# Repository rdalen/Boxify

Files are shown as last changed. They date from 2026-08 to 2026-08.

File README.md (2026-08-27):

# 📦 Boxify

**Parametric Electronics Enclosure Framework (PEEF)** for Onshape.

Boxify provides a reusable, configuration-driven framework for creating custom enclosures around PCB-based electronics

Instead of designing an enclosure directly around a specific PCB, Boxify separates the electronics from the enclosure through a **parametric Adapter Plate**.

The result is a reusable enclosure architecture that can adapt to different PCB designs and configurations.

### 📖 Boxify on Instructables

Want a more visual introduction to Boxify?

Check out the Boxify [Instructable](https://www.instructables.com/-Boxify-a-Parametric-Electronics-Enclosure-Framewo) for a step-by-step introduction to the Boxify concept and workflow.

---


<p align="center"><i>Boxify Enclosure design</i></p>

---

# 🔗 Boxify Onshape Document

The parametric CAD model is maintained in Onshape:

👉 **[Open Boxify in Onshape](https://cad.onshape.com/documents/2b9b04247ce552c5f277d796/w/c7290f51dafd6be38e8eb7a9/e/5737f0d6de4e250f9e54ff44)**

The GitHub repository contains the documentation and project history, while the Onshape document contains the parametric CAD model itself.

---

## 🧠 What is Boxify?

Boxify is designed around a simple principle:

> **The PCB defines the electronics. The Adapter Plate defines the mechanical interface. PS Enclosure defines what enclosure to build.**

The architecture separates the different responsibilities:

```text id="2a0p6m"
PCB / KiCad
     │
     │ detailed PCB STEP
     ▼
PS KiCadStep  <--- PCB Library
     │
     │ PCB + reusable PCB Type
     ▼
Adapter Plate
     │
     │ mechanical interface
     ▼
PS Enclosure  <--- Threaded Insert Library
     │
     │ user configuration
     ▼
Box Base + Box Lid
     │
     ▼
Assembly
```

This separation allows:

- The same PCB to be used with different enclosure configurations.
- The same enclosure architecture to support different PCB designs.
- PCB revisions to propagate through the mechanical design.
- Reusable PCB and hardware definitions to be maintained independently.
- Optional enclosure features to be dynamically enabled or suppressed.

---

# 🔗 KiCad Integration

Boxify integrates with KiCad through the PCB STEP export.

The imported STEP model represents the detailed physical PCB assembly.

Boxify uses a **Carrier / Passenger** architecture:

```text id="j3h6vz"
PCB Library
     │
     │ reusable PCB Type
     ▼
   Carrier
     ▲
     │
   Passenger
     │
     │ detailed geometry
     │
 KiCad STEP
```

The PCB Library provides the reusable PCB definition, while the imported STEP model provides the detailed representation of the actual PCB.

This allows the PCB STEP model to be updated independently without breaking the surrounding Boxify architecture, keeping the enclosure design reusable and parametric.

---

# 🏗 Core Architecture

The **Adapter Plate** is the central mechanical abstraction in Boxify.

It separates:

```text id="5q6x2v"
Electronics
    │
    ▼
PCB / KiCad
    │
    ▼
PS KiCadStep
    │
    ▼
Adapter Plate
    │
    ▼
PS Enclosure
    │
    ▼
Enclosure
```

The enclosure therefore does not need to depend directly on the internal structure of the PCB.

The Adapter Plate acts as the **contract between the PCB and the enclosure**.

---

# 📚 Documentation

The documentation is organized by responsibility.

### **[Getting Started](docs/getting-started.md)**
→ *How do I use Boxify?*

A practical introduction to the Boxify workflow, from importing a PCB to configuring and verifying an enclosure.

### **[Architecture](docs/architecture.md)**
→ *How is Boxify structured?*

Explains the overall architecture, responsibilities of each component and the flow of information through the framework.

### **[Configurations](docs/configurations.md)**
→ *How does configuration work?*

Explains user configuration, measured and derived variables, dynamic suppression and the configuration philosophy of Boxify.

### **[PCB Library](docs/pcb-library.md) and [KiCad Integration](docs/kicad-integration.md)**
→ *How do I bring my electronics into it?*

Explains the PCB Library, KiCad STEP integration and the Carrier / Passenger architecture.

### **[Adapter Plate](docs/adapter-plate.md)**
→ *How is the PCB separated from the enclosure?*

Explains the mechanical abstraction layer between the PCB and enclosure.

### **[Enclosure](docs/enclosure.md)**
→ *How is the enclosure generated?*

Explains the Box Base, Box Lid, fastening options, cut-outs, labels and dynamic feature suppression.

### **[Threaded Insert Library](docs/threaded-insert-library.md)**
→ *How are reusable fastening components handled?*

Explains reusable threaded insert definitions and their integration with PS Enclosure.

### **[Contributing](CONTRIBUTING.md)**
→ *How do I extend Boxify?*

Explains the development workflow, architecture principles, testing and contribution guidelines.

---

# ✨ Key Features

### 🧩 Parametric Enclosure

Generate a configurable Box Base and Box Lid from a single enclosure architecture.

### 🔌 KiCad STEP Integration

Use the actual PCB and component geometry exported from KiCad.

### 🚗 Carrier / Passenger Architecture

Separate the reusable PCB definition from the detailed imported STEP model.

### 🔧 Adapter Plate

Use a stable mechanical interface between electronics and enclosure.

### ⚙️ Centralized Configuration

Configure enclosure-related options from PS Enclosure.

### 🔩 Threaded Insert Library

Select reusable threaded insert definitions instead of hard-coding insert geometry into the enclosure.

### 🔄 Dynamic Suppression

Automatically enable or suppress optional features according to the selected configuration.

### 🔌 Interface Cut-outs

Define your own required enclosure cut-outs based on the available PCB/interface geometry. The PCB definition remains unchanged.

### 🏷️ Text Labels

Define your own enclosure-specific labels, independently of the PCB definition.

---

# 📐 Design Philosophy

Boxify follows a few fundamental principles:

### Separation of Responsibilities

Each part of the architecture has a clear purpose.

### Configure Design Intent

Configuration describes **what the user wants to build**, not how the CAD features are implemented.

### Measure Rather Than Duplicate

If geometry already contains the required information, derive or measure it rather than entering the same value again.

### Reusable Components

Reusable definitions belong in libraries.

### Stable References

Downstream geometry should rely on stable mechanical references rather than fragile implementation details.

### Minimal Coupling

The enclosure should depend on the Adapter Plate rather than directly on the PCB implementation.

### Dynamic Configuration

Optional features should be enabled or suppressed according to configuration.

---

# 🛠️ Built With

- **[Onshape](https://www.onshape.com/)** — Parametric CAD
- **[KiCad](https://www.kicad.org/)** — PCB design and STEP export
- **GitHub** — Version control and documentation

---

# 📜 Version History

Boxify follows an evolving configuration-driven architecture. See the [CHANGELOG](CHANGELOG.md) for the development history and architectural changes.

Boxify is currently based on the v2.x configuration-driven architecture, with ongoing improvements to the PCB and KiCad STEP integration.

---

# 🤝 Contributing

Contributions are welcome!

Before making changes, please read the [Contributing Guide](CONTRIBUTING.md) and familiarize yourself with the [Architecture](docs/architecture.md).

---

**Happy Boxifying! 🚀**

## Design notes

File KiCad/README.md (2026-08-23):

# KiCad Resources

These KiCad resources are provided to create PCB designs that match the mechanical definitions in the Boxify PCB Library.

## KiCad Templates

To use a Boxify KiCad template:

1. In KiCad, click **File > New Project from Template...** in the main menu.
2. Choose the **User Templates** source tab. This displays templates you have built or imported yourself.
3. Select one of the Boxify templates. Single-click an icon to view its description, layout constraints, or details.
4. Click **OK** once you have made your choice.
5. **Name and Save:** Provide a name for your design.
6. KiCad will automatically create a new project directory populated with pre-configured schematics, board layout, and design rules.

## KiKit Panelizing Plugin

To use one of the Boxify KiKit panelization configurations:

1. Open **KiCad PCB Editor** (standalone).
2. Start the **KiKit panelizing plugin** by clicking the menu button.
3. In KiKit, import the desired panelization configuration, for example:
   `KiKit panelize 2x PCB w49x100mm.json`
4. Browse for the **Input file**.
5. Browse for the **Output file**.
6. Click **Panelize**.

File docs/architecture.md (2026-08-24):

# 🏗 Architecture

Boxify is a **Parametric Electronics Enclosure Framework (PEEF)** built for Onshape.

The architecture separates the electronics from the mechanical enclosure by introducing an intermediate **Adapter Plate**.

This separation allows:

- The same PCB to be used with different enclosure configurations.
- The same enclosure architecture to support different PCB designs.
- PCB-specific geometry to remain independent from enclosure-specific geometry.
- Enclosure configuration to be managed from a single user-facing location.

The result is a modular, reusable and configuration-driven enclosure framework.

---

# 🔄 Workflow Overview

```text
PCB / KiCad
     │
     │ detailed PCB STEP
     ▼
PS KiCadStep  <--- PCB Library
     │
     │ PCB + reusable PCB Type
     ▼
Adapter Plate
     │
     │ mechanical interface
     ▼
PS Enclosure <--- Threaded Insert Library
     │
     │ user configuration
     ▼
Box Base + Box Lid
     │
     ▼
Assembly
```

The libraries support the stages where their reusable definitions are consumed:

- **PCB Library** provides the reusable PCB Type used by `PS KiCadStep`.
- **Threaded Insert Library** provides the insert definitions used by `PS Enclosure`.

The main mechanical design flow remains one-directional:

> **PCB → Adapter Plate → Enclosure → Assembly**

Changes to upstream geometry or configuration propagate downstream through the parametric architecture.

---

  

<p align="center"><i>From PCB design to Boxify Enclosure design</i></p>
---

# 🧩 Core Components

## PCB Library

The **PCB Library** contains reusable definitions of supported PCB Types.

In the Boxify architecture, the PCB Library provides the **Carrier** for the imported KiCad STEP model, which acts as the **Passenger**.

Each PCB definition can provide:

- PCB geometry
- Mounting hole locations
- PCB dimensions
- Reference geometry
- PCB-specific measured variables

The PCB Library contains information about the PCB itself and does not contain enclosure-specific configuration.

This separation allows the same PCB definition to be reused by different enclosure designs.

---



<p align="center"><i>Boxify PCB Library</i></p>

---

## PS KiCadStep

`PS KiCadStep` integrates a detailed PCB STEP model exported from KiCad with a reusable PCB Type from the PCB Library.

The architecture uses a **Carrier / Passenger** relationship:

```text
PCB Library
    │
    │ reusable PCB Type
    ▼
  Carrier
    ▲
    │
  Passenger
    │
    │ detailed KiCad STEP
    │
PS KiCadStep
```
*In Onshape terms; The KiCad STEP is mated to the PCB Type from the PCB library*

The PCB Library provides the stable, reusable reference geometry, while the imported STEP model provides the detailed representation of the actual PCB assembly.

This allows the detailed KiCad model to be used without making the enclosure dependent directly on the imported STEP geometry.

---

# 🔧 Adapter Plate

The **Adapter Plate** is the mechanical heart of Boxify.

It provides the interface between the PCB and the enclosure.

Its responsibilities include:

- Mounting the PCB.
- Positioning the PCB relative to the enclosure.
- Providing stable mechanical reference geometry.
- Defining mounting locations for enclosure features.
- Providing measured and derived geometry required by the enclosure.

The Adapter Plate deliberately separates the electronics from the enclosure.

The enclosure therefore does not need to understand the details of the PCB itself. It only needs the mechanical interface provided by the Adapter Plate.

This loose coupling is one of the fundamental principles of Boxify.

---

<p align="center">
  
<p>
<p align="center"><i>Boxify Adapter Plate</i></p>

---

# 📦 PS Enclosure

`PS Enclosure` is the **main user-facing configuration point** of Boxify.

Enclosure-related configuration is centralized here so that the user normally does not need to switch between Part Studios to configure the enclosure.

Typical configuration options include:

- PCB rotation
- Component side up or down
- Mounting side above or below the adapter plate
- Adapter Plate height
- Box height
- Box-wall, box-bottom and box-lid  thickness
- The PCB distance from the box-walls
- Lid fastening type
- Threaded insert configuration
- Interface cut-outs
- Text labels

Configuration variables and features can be shown, hidden or dynamically suppressed depending on the selected options.

This allows a single enclosure framework to generate different enclosure variants without manually editing downstream features.

---

<p align="center">


</p>
<p align="center"><i>Boxify Enclosure</i></p>

---

### 🧱 Box Base and Box Lid

The enclosure consists of two main components:

- **Box Base**
- **Box Lid**

Both are generated from the enclosure configuration and the mechanical references provided by the Adapter Plate.

Typical enclosure features include:

- Walls
- Bottom
- Lid
- Mounting lugs
- Screw pockets
- Threaded insert pockets
- Interface cut-outs
- Text labels

The Box Base and Box Lid are designed as a coordinated system because they always belong to the same enclosure configuration.

The selected configuration determines which features are required. Features that are not applicable can be dynamically suppressed.

---

# 🔩 Threaded Insert Library

The **Threaded Insert Library** contains reusable definitions for threaded inserts.

Each insert definition can contain:

- Insert dimensions
- Pocket geometry
- Installation requirements
- Configuration information

The library is consumed by **PS Enclosure**.

This keeps insert-specific geometry separate from the enclosure itself and allows different insert types to be supported without redesigning the enclosure features.

Threaded inserts can also be disabled when an enclosure does not require them.

---



<p align="center"><i>Boxify Treaded inserts Library</i></p>

---

# ⚙️ Configuration Architecture

A key principle in Boxify is that **configuration belongs to the stage where the information is defined**.

The **PCB Type** is selected when the PCB Library is derived into **PS KiCadStep**. This defines which PCB is used by the Boxify system.

The remaining **enclosure-related user configuration** is centralized in **PS Enclosure**.

```text
                 PCB Definition
                       │
                       ▼
              ┌─────────────────┐
              │  PS KiCadStep   │
              │                 │
              │ Select PCB Type │
              │ from PCB Library│
              └────────┬────────┘
                       │
                       ▼
              ┌─────────────────┐
              │ PS AdapterPlate │
              │                 │
              │ PCB-derived     │
              │ information     │
              └────────┬────────┘
                       │
                       ▼
              ┌─────────────────┐
              │   PS Enclosure  │
              │                 │
              │ Enclosure       │
              │ configuration   │
              └────────┬────────┘
                       │
          ┌────────────┼────────────┐
          ▼            ▼            ▼
      Box Base      Box Lid     Insert Library
```
This separation is important because each stage has a different responsibility

### PCB definition

The PCB Library contains the available PCB definitions.

In PS KiCadStep, the user selects the required PCB Type when deriving the PCB Library. This selection determines which PCB definition is carried forward into the rest of Boxify.

The PCB Type is therefore not an enclosure configuration option.

### Enclosure configuration

The user-facing configuration in PS Enclosure controls how the enclosure should be built around the selected PCB, for example:

- Box height
- Adapter height
- Wall thickness
- PCB distance from the box walls
- Lid fastening
- Insert option
- PCB orientation

The enclosure does not need a separate PCB Type selection because that information has already been defined upstream.

### Engineering and measured variables

Other variables describe what the geometry provides, rather than what the user wants to configure, for example:

- PCB dimensions
- Mounting-hole positions
- Derived reference locations
- Measured component clearance

Whenever possible, engineering information is measured or derived from existing geometry rather than entered manually.

This separation keeps the PCB definition, mechanical adaptation, and enclosure configuration independent, reducing duplication and maintenance when new PCB types are added.

---

# 🔁 Parametric Propagation

Boxify is designed so that information flows through the architecture rather than being duplicated.

```text
PCB / KiCad
     │
     ▼
PS KiCadStep
     │
     ▼
Adapter Plate
     │
     ▼
PS Enclosure
     │
     ▼
Box Base + Box Lid
```

For example:

1. A PCB STEP model provides the actual PCB assembly.
2. The PCB Library provides the reusable PCB geometry and reference.
3. The Adapter Plate establishes the mechanical interface.
4. PS Enclosure uses that interface together with the selected configuration.
5. Box Base and Box Lid are generated from those references.

When upstream geometry changes, downstream geometry can adapt automatically.

This reduces duplicated dimensions and minimizes manual updates.

---

# 🎯 Design Principles

Boxify follows several guiding principles.

## Separation of Responsibilities

Each Part Studio and library has a clearly defined purpose.

PCB-related information belongs to the PCB architecture.

Mechanical interface information belongs to the Adapter Plate.

Enclosure configuration and generation belong to PS Enclosure.

Reusable insert definitions belong to the Threaded Insert Library.

---

## Centralized User Configuration

User-facing enclosure configuration should be available from **PS Enclosure**.

The user should not need to edit downstream Part Studios or manually modify Derive features during normal configuration.

---

## Reusable Components

Components should be reusable across multiple projects whenever possible.

Libraries are used to separate reusable definitions from project-specific geometry.

---

## Parametric First

Geometry should adapt through parameters and configuration rather than manual editing.

---

## Measure Rather Than Duplicate

Whenever geometry already contains the required information, measure or derive it instead of entering the same information again.

This reduces inconsistencies and makes the model more robust to changes.

---

## Stable References

Use stable reference geometry and derived parts instead of recreating geometry.

This keeps relationships between the PCB, Adapter Plate and enclosure predictable.

---

## Loose Coupling

The enclosure should depend on the **mechanical interface** rather than directly on PCB implementation details.

The Adapter Plate provides this abstraction layer.

---

## Dynamic Configuration

Features that are not required by a selected configuration should be automatically suppressed where practical.

This keeps the generated model clean while allowing one framework to support many enclosure variants.

---

## Modular Growth

New functionality should extend the framework without requiring existing designs to be fundamentally redesigned.

Libraries and configuration-driven features should be preferred over project-specific hard-coded geometry.

---

# 🧠 The Boxify Architecture in One Sentence

> **Boxify separates the PCB from the enclosure through an Adapter Plate, while PS Enclosure provides centralized configuration to generate a complete parametric enclosure from reusable libraries and derived mechanical references.**

---

# 📚 Related Documentation

For implementation details, see:

- 📄 [Getting Started](getting-started.md)
- 📄 [PCB Library](pcb-library.md)
- 📄 [Adapter Plate](adapter-plate.md)
- 📄 [Enclosure](enclosure.md)
- 📄 [Threaded Insert Library](threaded-insert-library.md)
- 📄 [KiCad Integration](kicad-integration.md)
- 📄 [Configurations](configurations.md)

---

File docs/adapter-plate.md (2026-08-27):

# 🔧 Adapter Plate

## 🧠 Purpose

The **Adapter Plate** is the mechanical interface between the PCB and the enclosure.

It is one of the fundamental concepts of the Boxify architecture.

Instead of connecting the enclosure directly to a specific PCB design, Boxify connects the enclosure to an **Adapter Plate**.

This creates a stable mechanical abstraction layer between the electronics and the enclosure.

```text id="6m7n4r"
PCB
 │
 │ PCB-specific geometry
 ▼
Adapter Plate
 │
 │ standardized mechanical interface
 ▼
Enclosure
```

This separation allows the PCB and enclosure to evolve independently.

---

<p align="center"><i>Adapter Plate with the PCB Library Entry</i></p>

---

# 🏗 Position in the Boxify Architecture

```text id="r0g2h5"
PCB / KiCad
     │
     │ detailed STEP
     ▼
PS KiCadStep  <--- PCB Library
     │
     │ PCB definition
     ▼
Adapter Plate
     │
     │ mechanical interface
     ▼
PS Enclosure  <--- Threaded Insert Library
     │
     │ user configuration
     ▼
Box Base + Box Lid
     │
     ▼
Assembly
```

The Adapter Plate is therefore the **bridge between the PCB definition and the enclosure generator**.

---

# 🔗 The Mechanical Abstraction Layer

The Adapter Plate hides PCB-specific implementation details from the enclosure.

The enclosure does not need to know:

- Which CAD system was used to design the PCB.
- How the PCB STEP model is structured.
- Which components are present.
- How the PCB Type in the PCB Library was created.

It only needs the mechanical information provided by the Adapter Plate.

This is a key Boxify design principle:

> **The enclosure depends on the mechanical interface, not directly on the electronics.**

---

# 🧩 Adapter Plate Responsibilities

The Adapter Plate is responsible for establishing the mechanical relationship between the PCB and the enclosure.

Typical responsibilities include:

- PCB positioning
- PCB mounting
- Mounting-hole locations
- PCB reference geometry
- Enclosure mounting references
- Adapter Plate dimensions
- Reference Mate Connectors
- Mechanical interface geometry

The exact implementation can evolve, but the responsibility remains the same:

> **Translate PCB-specific geometry into a stable enclosure interface.**

---

# 📐 PCB Interface

The PCB side of the Adapter Plate is driven by the PCB definition provided by **PS KiCadStep**.

The Adapter Plate uses the PCB references to establish the correct position and orientation of the PCB.

Typical references include:

- PCB outline
- Mounting holes
- PCB origin
- Mounting plane
- Reference Mate Connector
  
The KiCad STEP is positioned as part of the Derive operation.

Therefore, `pcbThickness` and `pcbMountAdjust` are resolved before the KiCad STEP is derived into the Adapter Plate.

The Adapter Plate therefore adapts automatically to the selected PCB and its Passenger.

---

# 🧱 Enclosure Interface

The enclosure side of the Adapter Plate provides stable references for the Box Base and Box Lid.

These references can include:

- Adapter Plate outline
- Mounting locations
- Thickness
- Lug positions
- Enclosure reference planes
- Other mechanical reference geometry

The enclosure uses these references to generate the surrounding walls and other enclosure features.

---

# 📏 Measured and Derived Geometry

Where possible, Adapter Plate information should be **measured or derived from existing geometry** rather than manually duplicated.

Measured from geometry
- PCB length
- PCB width
- mounting-hole positions
- hole diameter

Defined PCB information
- PCB thickness

For example:

```text id="v7t5a3"
PCB geometry
     │
     ├── PCB dimensions
     ├── Mounting holes
     └── Reference position
             │
             ▼
       Adapter Plate
             │
             ├── interface geometry
             ├── mounting references
             └── measured dimensions
                     │
                     ▼
                PS Enclosure
```

This reduces the number of independent dimensions that need to be maintained.

---

# ⚙️ Configuration

The Adapter Plate should contain **mechanical information**, not general enclosure configuration.

Some Adapter Plate-related values may be exposed as user configuration through **PS Enclosure**, for example:

- Distance between the PCB and the edge of the Adapter Plate
- PCB orientation
- Component side up or down
- Mounting side above or below the adapter plate

The important distinction is that the user makes these choices from **PS Enclosure**, while the Adapter Plate provides the geometry required to implement them.

The user should not normally need to edit the Adapter Plate directly.

---

# 🔄 Configuration Flow

The overall relationship is:

```text id="5brz4p"
                  User
                   │
                   │ configuration
                   ▼
             PS Enclosure
                   │
                   │ selected PCB
                   ▼
              PS KiCadStep
                   │
                   │ PCB definition
                   ▼
             Adapter Plate
                   │
                   │ mechanical interface
                   ▼
          Box Base + Box Lid
```

This keeps user configuration centralized while allowing the Adapter Plate to remain a reusable mechanical component.

---

# 🧭 Reference Strategy

Stable references are important because the Adapter Plate is used by downstream enclosure geometry.

References should therefore be:

- Predictable
- Clearly named
- Based on stable geometry
- Independent of unnecessary implementation details

Where possible, downstream features should reference the Adapter Plate rather than directly referencing imported PCB geometry.

This reduces the risk of broken references when the PCB or KiCad STEP model changes.

---

# 🔄 PCB Updates

One of the main benefits of the Adapter Plate architecture is that PCB updates can propagate through the system.

A typical update looks like:

```text id="6b3n2q"
KiCad PCB
    │
    ▼
New STEP
    │
    ▼
PS KiCadStep
    │
    ▼
Adapter Plate
    │
    ▼
PS Enclosure
    │
    ▼
Updated Base + Lid
```

If the PCB remains compatible with the existing mechanical interface, the enclosure architecture does not need to be redesigned.

If PCB dimensions or mounting locations change, the Adapter Plate adapts the new PCB definition to the enclosure.

---

# 🧠 Design Principles

## Mechanical Abstraction

The Adapter Plate hides PCB-specific details from the enclosure.

## Stable Interface

The Adapter Plate provides predictable references for downstream enclosure geometry.

## Reusable

The same enclosure architecture can be used with different PCB definitions as long as they can be represented through the Adapter Plate interface.

## Derived Where Possible

Mechanical information should be measured or derived rather than duplicated.

## Minimal Coupling

The Adapter Plate should depend on the PCB definition, while the enclosure should depend primarily on the Adapter Plate.

## Centralized Configuration

User-facing configuration belongs in PS Enclosure rather than being distributed across Part Studios.

---

# 🎯 Result

The Adapter Plate allows Boxify to treat the electronics and enclosure as two separate design domains connected by a well-defined mechanical interface.

```text id="h7q4xm"
       ELECTRONICS DOMAIN
              │
              ▼
       PCB / KiCad
              │
              ▼
       PS KiCadStep
              │
              ▼
       ┌──────────────┐
       │   Adapter    │
       │    Plate     │
       └──────┬───────┘
              │
              ▼
       MECHANICAL DOMAIN
              │
              ▼
        PS Enclosure
              │
              ▼
       Box Base + Lid
```

The key principle is:

> **The Adapter Plate is the contract between the PCB and the enclosure.**

The PCB side defines the electronics and their mechanical requirements.

The enclosure side consumes a stable mechanical interface.

This separation is what allows Boxify to remain parametric, reusable and adaptable.

---

# 📚 Related Documentation

- 📄 [Getting Started](getting-started.md)
- 📄 [Architecture](architecture.md)
- 📄 [PCB Library](pcb-library.md)
- 📄 [Enclosure](enclosure.md)
- 📄 [Threaded Insert Library](threaded-insert-library.md)
- 📄 [KiCad Integration](kicad-integration.md)
- 📄 [Configurations](configurations.md)

---

**Happy Boxifying! 🚀**

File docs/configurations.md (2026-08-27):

# 📄 Configurations

## 🧠 Purpose

Configurations allow Boxify to generate different enclosure variants from a single parametric model.

Instead of maintaining separate designs for different combinations of PCB, dimensions, mounting methods or fastening options, Boxify uses configuration variables to define **what the user wants to build**.

The goal is to keep the enclosure configuration:

- Centralized
- Meaningful
- Easy to understand
- Independent of implementation details
- Reusable across enclosure variants

---

# 🎯 Configuration Philosophy

Every user-facing configuration option should answer one simple question:

> **"What do I want to build?"**

Configurations should describe the **design intent**, not how the model is constructed internally.

For example:

- `boxHeight` describes the desired enclosure height.
- `wallThickness` describes the desired wall thickness.
- `lidFasteningType` describes how the lid should be secured.

The user should not need to know which sketches, features or Derive operations are used to create the resulting geometry.

---

# 🏗 Configuration Architecture

In Boxify, user-facing enclosure configuration is centralized in **PS Enclosure**.

```text
                         User Configuration
                                │
                                ▼
                        ┌───────────────┐
                        │  PS Enclosure │
                        └───────┬───────┘
                                │
              ┌─────────────────┼─────────────────┐
              │                 │                 │
              ▼                 ▼                 ▼
        PCB information   Adapter Plate     Insert definition
              │                 │                 │
       PCB Library        derived/measured   Threaded Insert
                            geometry            Library
              │                 │                 │
              └─────────────────┼─────────────────┘
                                ▼
                       Box Base + Box Lid
```

This creates a clear distinction between:

### User configuration

Values that define the desired enclosure.

### Library definitions

Reusable definitions supplied by the PCB Library and Threaded Insert Library.

### Derived and measured information

Engineering values obtained from existing geometry.

This separation prevents configuration from becoming a collection of duplicated dimensions and implementation-specific settings.

---

# ⚙️ PS Enclosure Configuration

**PS Enclosure** is the primary user-facing configuration point.

Typical configuration options include:

### PCB

- PCB rotation
- Component side up or down
- Mounting side above or below the adapter plate

*Note: PCB Type is not an enclosure configuration option. It is selected when deriving the PCB Library entry in PS KiCadStep.*

### Adapter Plate

- Adapter Plate height
- Other enclosure-relevant interface settings

### Enclosure

- Box height
- Wall thickness
- Bottom thickness
- Lid thickness

### Lid

- Lid fastening type

### Threaded Inserts

- Insert configuration
- Insert enable/disable

### Interface Features

- Cut-out options
- Text label options

The exact set of available options can evolve as Boxify gains new capabilities.

---

# 🔩 Lid Fastening Configuration

The lid fastening system is controlled through a dedicated configuration option.

The configuration describes the **intended fastening method**, rather than exposing the individual features used to create it.

For example:

- None
- Counterbore screws
- Countersunk screws
- Selftapping screws

The selected fastening type controls which related geometry is required.

Features that are not applicable to the selected configuration can be **dynamically suppressed**.

This allows several lid fastening variants to be generated from the same enclosure model.

---

# 🔩 Threaded Insert Configuration

The **Threaded Insert Library** provides reusable definitions for supported inserts.

PS Enclosure selects the required insert definition and uses it when generating the enclosure.

The configuration can also disable threaded inserts completely.

```text
Threaded Insert Library
          │
          │ insert definition
          ▼
    PS Enclosure
          │
          │ configuration
          ▼
   Insert pockets / lugs
```

The enclosure therefore does not need to contain a separate hard-coded implementation for every insert type.

---

# 🔄 Dynamic Configuration

Boxify uses configuration to control not only dimensions but also **feature availability**.

Some configuration variables and features are only relevant when another option is enabled.

For example:

```text
Insert configuration
       │
       ├── No Inserts
       │       └── Insert-related features suppressed
       │
       └── Inserts enabled
               └── Insert configuration becomes relevant
```

Similarly, lid fastening options can enable the geometry required for the selected fastening method while suppressing geometry that is not needed.

This keeps the generated model clean and prevents irrelevant configuration options from being exposed to the user.

---

# 📏 Measured Variables

Not every value in Boxify should be configurable.

Whenever a value can be obtained reliably from existing geometry, it should preferably be **measured or derived** rather than entered manually.

Examples include:

- PCB dimensions
- PCB mounting-hole positions
- Adapter Plate dimensions
- Adapter Plate thickness
- Lug dimensions
- Internal reference dimensions

Measured and derived variables provide information to downstream features without requiring the user to maintain duplicate values.

This improves model robustness and reduces the possibility of inconsistent configuration.

---

# 🔗 Configuration vs. Derived Information

It is important to distinguish between **configuration variables** and **engineering variables**.

### Configuration variables

Define what the user wants.

Examples:

```text
boxHeight
adapterPlateHeight
wallThickness
lidFasteningType
pcbRotation
insertConfiguration
```

### Measured / derived variables

Describe information already available in the model.

Examples:

```text
pcbWidth
pcbLength
mountingHolePosition
adapterPlateThickness
lugHeight
```

The general rule is:

> **If the user needs to choose it, configure it. If the model already knows it, derive or measure it.**

Some PCB properties are defined inputs rather than measured geometry.

PCB thickness is one such property because it is required to position the detailed KiCad STEP before it enters the Adapter Plate.

```text
PCB definition
├── PCB length       → measured / derived
├── PCB width        → measured / derived
├── mounting holes   → measured / derived
└── PCB thickness    → defined input (`vs_pcbThickness`)

             ↓

        KiCad STEP
             ↓
      Adapter Plate
```

---

# 🧭 Configuration Flow

Configuration information flows through the Boxify architecture without requiring the user to manually propagate values between Part Studios.

```text
PCB / KiCad
     │
     ▼
PS KiCadStep  <--- PCB Library
     │
     ▼
Adapter Plate
     │
     │ derived / measured geometry
     ▼
PS Enclosure  <--- Threaded Insert Library
     │
     │ user configuration
     ▼
Box Base + Box Lid
```

The libraries provide reusable definitions, while PS Enclosure combines those definitions with the enclosure configuration.

This keeps the configuration workflow simple while preserving the modularity of the underlying architecture.

---

# 🧠 Configuration Guidelines

When adding new configuration options, follow these principles.

## Configure Intent

Expose parameters that describe the desired result.

Good examples:

- Box height
- Adapter Plate height
- Wall thickness
- PCB rotation
- Lid fastening type
- Insert option

Avoid exposing implementation-specific values unless the user genuinely needs to control them.

---

## Avoid Duplicate Information

A value should preferably be entered only once.

If it can be measured or derived from geometry, it should not become another independent configuration variable.

This reduces the risk of conflicting values.

---

## Centralize User Configuration

User-facing enclosure configuration belongs in **PS Enclosure**.

The user should not normally need to:

- Switch between Part Studios
- Edit Derive features
- Modify internal sketches
- Maintain duplicate configuration values

The underlying Part Studios should consume the configuration rather than require the user to manage it manually.

---

## Keep Libraries Reusable

Libraries should contain reusable definitions rather than project-specific configuration.

For example:

- PCB Library → reusable PCB definitions
- Threaded Insert Library → reusable insert definitions

The enclosure selects and consumes these definitions.

---

## Prefer Meaningful Names

Configuration variable names should describe their purpose and design intent.

Examples:

```text
boxHeight
wallThickness
adapterPlateHeight
lidFasteningType
insertConfiguration
```

Avoid names that expose implementation details or the internal feature structure.

---

## Separate Configuration from Engineering Variables

Do not expose measured or derived engineering values as user configuration unless there is a genuine design reason to do so.

This keeps the user interface focused on decisions the user actually needs to make.

---

## Use Dynamic Suppression Where Appropriate

When a configuration option makes a feature irrelevant, consider dynamically suppressing that feature.

This is particularly useful for:

- Optional threaded inserts
- Lid fastening methods
- Optional cut-outs
- Optional labels
- Other mutually exclusive enclosure features

Dynamic suppression allows one parametric model to represent several valid design variants without creating separate feature trees for each variant.

---

# 🚀 Configuration as a Design System

Boxify configuration is more than a collection of dimensions.

It defines a **design system** in which:

```text
User intent
     │
     ▼
Configuration
     │
     ▼
Reusable definitions
     │
     ▼
Derived / measured geometry
     │
     ▼
Dynamic feature selection
     │
     ▼
Generated enclosure
```

This is what allows Boxify to behave as a **configuration-driven enclosure generator** rather than a collection of independently configured Part Studios.

---

# 📚 Related Documentation

- 📄 [Getting Started](getting-started.md)
- 📄 [Architecture](architecture.md)
- 📄 [PCB Library](pcb-library.md)
- 📄 [Adapter Plate](adapter-plate.md)
- 📄 [Enclosure](enclosure.md)
- 📄 [Threaded Insert Library](threaded-insert-library.md)
- 📄 [KiCad Integration](kicad-integration.md)

---

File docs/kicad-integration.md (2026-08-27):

# 📄 KiCad Integration

## 🧠 Purpose

Boxify supports custom PCBs designed in **KiCad** by importing the PCB as a STEP model.

This allows the actual mechanical representation of the PCB and its components to be integrated into the reusable Boxify enclosure architecture.

The KiCad STEP model provides the detailed geometry of the electronics, while Boxify provides the reusable mechanical framework around it.

The integration therefore separates:

- **Electronic design** → KiCad
- **Detailed PCB geometry** → imported STEP model
- **Reusable PCB definition** → PCB Library
- **Mechanical interface** → Adapter Plate
- **Enclosure configuration** → PS Enclosure

This keeps the PCB design as the source of truth for the electronics while allowing Boxify to generate the surrounding enclosure parametrically.

---

# 🔄 Position in the Boxify Workflow

```text
KiCad PCB
    │
    │ Export STEP
    ▼
PCB STEP Model
    │
    │ Import into Onshape
    ▼
PS KiCadStep  <--- PCB Library
    │
    │ PCB + reusable PCB type
    ▼
Adapter Plate
    │
    │ mechanical interface
    ▼
PS Enclosure
    │
    │ user configuration
    ▼
Box Base + Box Lid
    │
    ▼
Assembly
```

The important distinction is:

> **The KiCad STEP model provides the detailed geometry of the electronics; the PCB Library provides the reusable PCB definition used by the Boxify architecture.**

---

# 📤 Exporting from KiCad

Export the PCB from KiCad as a STEP model.

For best results:

- Include all mounted components that should be represented mechanically.
- Export using millimetres.
- Ensure component orientation is correct.
- Make sure the PCB origin is always in the center of the PCB board
- Keep the PCB origin and coordinate system consistent between STEP exports.
- Include accurate 3D models for components that affect the enclosure.

The exported STEP model should represent the mechanical state of the electronic assembly that needs to fit inside the enclosure.

### ⚠️PCB Origin

When exporting from KiCad, make sure the PCB origin is positioned at the center of the PCB. Boxify uses the centered Mate Connector in the PCB Library as the reference for mating the imported STEP model.

What is important is that the origin and coordinate system remain consistent between PCB revisions.

This allows an updated STEP model to replace the previous model without unexpectedly changing the relationship between the PCB, Adapter Plate and enclosure.

---

<p align="center">

</p>
<p align="center"><i>Check Board center origin in the STEP export</i></p>
---

# 📥 Importing the STEP Model

Import the STEP model into the Boxify Onshape document.
If necessary, align the components that interface with the enclosure front to the same level in KiCad (before exporting) or manually in Onshape after importing

The imported model is treated as the **Passenger** in the Boxify carrier/passenger architecture.

The passenger represents the detailed physical PCB assembly:

- PCB
- Components
- Connectors
- Mechanical features
- Other relevant 3D models

The passenger is not intended to become the parametric definition of the enclosure.

Instead, it provides the detailed geometry required to represent the actual electronics.

---



<p align="center"><i>Import the Step file.</i></p>

---
### 🧰 KiCad Resources

Boxify provides matching KiCad project templates for the supported PCB Types, as well as KiKit configurations for panelized PCB designs.

See [KiCad Resources](../KiCad/README.md)

---

# 🚗 Carrier / Passenger Architecture

Boxify separates the detailed imported STEP model from the reusable PCB definition.

```text
                 PCB Library
                     │
                     │ reusable PCB Type
                     ▼
                  CARRIER
                     │
                     │
                     ▲
                     │
                  PASSENGER
                     │
                     │ detailed geometry
                     │
               KiCad STEP
```

### Carrier

The selected PCB Type from the PCB Library acts as the **Carrier**.
Make sure the selected PCB Type **has the same dimensions as the PCB in the imported STEP model**.

In fact, it is the carrier that provides the stable reusable PCB definition used by the Boxify architecture.

The carrier can provide:

- PCB reference geometry
- PCB dimensions
- Mounting references
- Reference Mate Connector
- PCB-specific configuration information

### Passenger

The imported **KiCad STEP model** acts as the **Passenger**.

It provides:

- Actual PCB geometry
- Mounted components
- Connector geometry
- Detailed mechanical representation

The passenger can therefore be replaced when the PCB design changes without redesigning the Boxify architecture.

---

# 🧩 Creating a Composite Part

Imported STEP models can contain many individual parts.

Creating a **Composite Part** combines the imported PCB components into a single reusable reference.

This provides several advantages:

- Simplified selection
- Easier deriving
- Stable references
- Cleaner model organisation
- Easier handling of imported assemblies

To do so: 
- Open the STEP Model in Boxify
- Create a feature **composite**
- Select all the (sub)parts of the STEP model
- Check **closed**

---

<p align="center">

</p>    
<p align="center"><i>Create a Composite part</i></p>

The Composite Part represents the complete imported PCB assembly as a single mechanical reference.

Sadly, the Composited PCB is looking a little gray now… 😉

---


<p align="center"><i>Composite part with aligned front-attached components.</i></p>

---

# 🏗 Creating a PCB Library Entry

After importing and preparing the STEP model:

2. Open **PS KiCadStep**.
3. Derive the imported Composite Part into PS KiCadStep.
4. Select an appropriate PCB Type from the **PCB Library**. Make sure the selected PCB Type has the same dimensions as the PCB in the imported STEP model
5. Use the PCB Library PCB as the Carrier.
6. Use the imported STEP geometry as the Passenger.
7. Establish the required relationship between the two.

The resulting PCB definition becomes reusable within Boxify.

```text
KiCad STEP
    │
    ▼
Composite Part
    │
    ▼
PS KiCadStep
    │
    ├───────────────┐
    │               │
    ▼               ▼
Passenger        Carrier
STEP geometry    PCB Library PCB Type
    │               │
    └───────┬───────┘
            ▼
      PCB definition
            │
            ▼
       Adapter Plate
```

---


<p align="center"><i>The new PCB Library entry.</i></p>

---

### 📐 PCB Library PCB Type

The selected PCB Type from the PCB Library should represent the PCB that the imported STEP model belongs to.

The prototype provides the reusable reference information required by the downstream Boxify architecture.

The imported STEP model supplies the detailed representation of the actual electronic assembly.

This separation means that the enclosure does not need to depend directly on the internal structure of the imported STEP model.

---

### 📐 PCB Thickness and STEP Positioning

The PCB thickness is defined in the Variable Studio **General Settings** as `vs_pcbThickness`.

It is not measured from the imported KiCad STEP and is not part of the PCB Library configuration table.

The mounting adjustment is calculated from the PCB configuration and applied when the KiCad STEP is derived into the Adapter Plate.

This means the KiCad STEP enters the Adapter Plate in its required mounting position without requiring a downstream transformation of the imported Composite Part.

This keeps the KiCad STEP integration independent of transformations applied to the imported composite geometry and makes the workflow more robust when the STEP model is replaced or updated.

---

# 🔄 Updating the PCB

When the PCB design changes:

1. Update the PCB in KiCad.
2. Export a new STEP model.
3. Replace the existing imported STEP model in Onshape.
4. Update the Composite Part if necessary.
5. Verify the Passenger / Carrier relationship.
6. Regenerate the affected geometry.
7. Verify the resulting enclosure in the Assembly.

The Boxify architecture allows the updated PCB geometry to propagate through the Adapter Plate and enclosure.

The PCB Type from the PCB Library should only need to be changed when the **PCB definition itself** changes, rather than simply because the detailed STEP model has been updated.

---

<p align="center">

<p>
<p align="center"><i>Updating the STEP model</i></p>

---

# 🔁 Typical PCB Revision Workflow

```text
KiCad
  │
  │ PCB revision
  ▼
Export new STEP
  │
  ▼
Replace Passenger
  │
  ▼
Update Composite Part
  │
  ▼
PS KiCadStep
  │
  │ Carrier remains reusable
  ▼
Adapter Plate
  │
  ▼
PS Enclosure
  │
  ▼
Updated Box Base + Box Lid
  │
  ▼
Assembly verification
```

This makes the imported STEP model replaceable while preserving the reusable Boxify architecture around it.

---

# ⚙️ Configuration

PCB-related configuration is intentionally kept separate from enclosure configuration.

The PCB Library and PS KiCadStep provide the information required to define the PCB and its mechanical relationship.

Once the PCB is available to Boxify, enclosure-related choices are made in **PS Enclosure**.

Examples include:

- PCB rotation
- Component side up or down
- Mounting side above or below the adapter plate
- Adapter Plate height
- Box height
- Lid fastening
- Threaded inserts
- Cut-outs
- Labels

The user should therefore not need to modify PS KiCadStep when configuring the enclosure.

The PCB Type is selected in the Derive feature when the PCB Library is brought into PS KiCadStep.
<p align="center">

</p>
<p align="center"><i>Select PCB Type in the Derive feature</i></p>

---

# 💡 Best Practices

### Keep the STEP model consistent

Keep the PCB origin and coordinate system consistent between revisions.

### Include accurate component models

Components that affect enclosure clearance should have accurate 3D models in KiCad.

### Use a Composite Part

Use a Composite Part to simplify the imported PCB assembly.

### Keep the Carrier reusable

The PCB Library PCBs should represent the reusable PCB definition rather than a particular imported STEP revision.

### Create an Onshape Version

Create a Version before replacing a PCB STEP model when making a significant PCB revision.

### Verify the Assembly

After updating the PCB, verify:

- PCB position
- Component clearances
- Adapter Plate alignment
- Mounting locations
- Cut-outs
- Lid clearance
- Overall enclosure fit

---

# ⚠️ Known Limitations

The quality of the resulting enclosure depends on the quality of the imported STEP model.

Current limitations include:

- Missing KiCad 3D models will not appear in the enclosure.
- Incorrect component orientation can result in incorrect mechanical geometry.
- Large PCB assemblies can increase Onshape regeneration time.
- Mechanical features that are not represented in the STEP model cannot be detected automatically.
- Changes to the physical PCB definition may require an updated PCB Library PCB.

---

# 🧠 Design Principle

The KiCad integration follows one important rule:

> **KiCad remains the source of truth for the electronics; Boxify remains the source of truth for the enclosure.**

The STEP model connects the two.

```text
┌──────────────┐
│    KiCad     │
│              │
│ PCB design   │
└──────┬───────┘
       │
       │ STEP
       ▼
┌──────────────┐
│ PS KiCadStep │
│              │
│ Carrier +    │
│ Passenger    │
└──────┬───────┘
       │
       ▼
┌──────────────┐
│ Adapter      │
│ Plate        │
└──────┬───────┘
       │
       ▼
┌──────────────┐
│ PS Enclosure │
│              │
│ Configuration│
└──────┬───────┘
       │
       ▼
 Box Base + Lid
```

This separation is what allows Boxify to remain reusable while still generating an enclosure that accurately represents the actual PCB assembly.

---

# 📚 Related Documentation

- 📄 [Getting Started](getting-started.md)
- 📄 [Architecture](architecture.md)
- 📄 [PCB Library](pcb-library.md)
- 📄 [Adapter Plate](adapter-plate.md)
- 📄 [Enclosure](enclosure.md)
- 📄 [Threaded Insert Library](threaded-insert-library.md)
- 📄 [Configurations](configurations.md)

---

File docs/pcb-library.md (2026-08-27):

# 📚 PCB Library

## 🧠 Purpose

The **PCB Library** contains reusable definitions of supported PCB Types for use within the Boxify framework.

A PCB Library entry provides the stable mechanical reference that Boxify uses to connect a (KiCad) PCB design to the Adapter Plate and, ultimately, the enclosure.

The PCB Library is deliberately separated from the detailed PCB STEP model exported from KiCad.

The library provides the **Carrier**.

The imported KiCad STEP model provides the **Passenger**.

Together they form the PCB definition used by the Boxify architecture.

---

<p align="center">

</p>
<p align="center"><i>Boxify PCB Library</i></p>

---

# 🏗 Position in the Boxify Architecture

```text id="n2n3p5"
PCB / KiCad
     │
     │ detailed STEP
     ▼
PS KiCadStep  <--- PCB Library
     │
     │ PCB + reusable PCB Type
     ▼
Adapter Plate
     │
     │ mechanical interface
     ▼
PS Enclosure  <--- Threaded Insert Library
     │
     ▼
Box Base + Box Lid
```

The PCB Library is therefore part of the **PCB definition stage**, not the enclosure configuration stage.

---

# 🚗 Carrier / Passenger Architecture

The PCB Library prototype acts as the **Carrier** for the imported KiCad STEP model.

```text id="9y3c2v"
                PCB Library
                     │
                     │ reusable PCB Type
                     ▼
                  CARRIER
                     │
                     ▲
                     │
                  PASSENGER
                     │
                     │ detailed PCB assembly
                     │
                 KiCad STEP
```

### Carrier

The Carrier provides the stable, reusable PCB reference.

It can contain:

- PCB outline
- Mounting-hole geometry
- Reference geometry
- Mate Connector
- PCB dimensions
- PCB-specific measured or derived variables

### Passenger

The Passenger is the detailed PCB assembly imported from KiCad.

It can contain:

- PCB
- Components
- Connectors
- Mounting hardware
- Other mechanical details represented by the KiCad STEP export

The Passenger can be replaced when the PCB revision changes, while the Carrier remains the reusable reference whenever the PCB definition itself has not changed.

---

# 🧩 What a PCB Library Entry Represents

A PCB Library entry represents a **specific PCB design definition** that can be reused by Boxify.

It should provide enough information for the downstream architecture to establish:

- PCB identity
- PCB coordinate system
- PCB outline
- Mounting locations
- Reference geometry
- Connection to the Adapter Plate

The library entry should not contain enclosure-specific information.

For example, the PCB Library should **not** define:

- Box height
- Wall thickness
- Lid fastening
- Threaded insert selection
- Enclosure labels
- Enclosure cut-outs

Those decisions belong to **PS Enclosure**.

---

# 📐 PCB Geometry

A PCB Library entry should contain the geometry required to establish the mechanical relationship between the PCB and the Adapter Plate.

Important reference geometry can include:

### PCB Outline

Defines the physical board boundary.

### Mounting Holes

Defines the locations used to mount the PCB.

### Reference Geometry

Provides stable references for downstream features.

### Mate Connector

Provides the primary coordinate and orientation reference used when positioning the PCB within the Boxify architecture.

The goal is to keep these references stable and predictable.

---

# 📏 PCB Variables

PCB-specific variables can be stored or derived as part of the PCB definition.

Examples include:

```text id="8j7o5c"
pcbWidth
pcbLength
mountingHoleDiameter
mountingHolePosition
pcbThickness (defined in the Variable Studio General Settings)
```

These values describe the PCB itself.

They should not be confused with enclosure configuration variables such as:

```text id="xv9c7a"
boxHeight
wallThickness
lidFasteningType
```

The general rule is:

> **PCB Library variables describe the PCB; PS Enclosure variables describe the enclosure.**

Please note: PCB thickness is defined in the Variable Studio **General Settings**. It is not part of the PCB Library configuration table.

The PCB Library configuration table defines the PCB type and its mechanical interface. `pcbThickness` is a general PCB property used by Boxify when positioning the PCB and KiCad STEP geometry.

---

# 🧭 Coordinate System

The PCB Library provides a stable coordinate system for the PCB.

The coordinate system should remain consistent between:

- PCB Library geometry
- KiCad STEP exports
- PS KiCadStep
- Adapter Plate references

When a new STEP revision is imported, the PCB should retain the same coordinate relationship whenever possible.

This makes PCB updates much more predictable.

---

## Supported PCB Types

Boxify provides two categories of PCB Types in the PCB Library: **Prototype** and **Panel**.

### Prototype PCB Types

Prototype types are intended for the pre-drilled universal prototyping boards (so-called perfboard) you buy in bulk packs to build and test temporary or permanent DIY electronics

Examples include:

- Prototype w20×80mm
- Prototype w30×70mm
- Prototype w40×60mm
- Prototype w50×70mm
- Prototype w60×80mm
- Prototype w70×90mm

These are generic example formats and can be replaced or extended with project-specific PCB dimensions.

<p align="center">

</p>
<p align="center"><i>ProtoType PCBs</i></p>

### Panel PCB Types

Panel types are intended for PCBs that are manufactured as part of a **100 × 100 mm production panel**.

The supported dimensions take into account a **2 mm mouse-bite gap** between adjacent PCBs:

| Panel Type | Panel Layout | Calculation |
|---|---:|---:|
| Panel w100×100mm | 1 × 1 | 100 |
| Panel w49×100mm | 2 × 1 | 2 × 49 + 2 = 100 |
| Panel w49×49mm | 2 × 2 | 2 × 49 + 2 = 100 |
| Panel w23.5×49mm | 4 × 2 | 4 × 23.5 + 3 × 2 = 100 |
| Panel w23.5×23.5mm | 4 × 4 | 4 × 23.5 + 3 × 2 = 100 |

These panel dimensions make it possible to design the enclosure for the **individual PCB** while using the same PCB definition when the design is panelized for manufacturing.

> **Note:** The panel dimensions assume a 100 × 100 mm manufacturing panel and a 2 mm separation between PCBs. Actual panelization rules may vary between PCB manufacturers.
 
<p align="center">

</p>
<p align="center"><i>100 × 100 mm manufacturing panel with 4x Panel w49×49mm PCBs</i></p>

---

### 🧰 Matching KiCad Templates

Matching KiCad project templates are provided for the supported PCB Types.

The template names correspond directly to the PCB Library names, making it easy to select the correct KiCad template for a Boxify PCB definition.

See [KiCad Resources](../KiCad/README.md)

---

### 🔲 KiKit Panelization

Matching KiKit panelization configurations are provided for the supported Panel PCB Types.

These configurations can be used to panelize the PCB according to the corresponding Boxify Panel PCB definition

See [KiCad Resources](../KiCad/README.md)

---

# 🔄 Creating a PCB Library Entry

A typical workflow is:

1. Export the PCB from KiCad as STEP.
2. Import the STEP model into Onshape.
3. Create a Composite Part if required.
4. Open **PS KiCadStep**.
5. Select (or create) the appropriate PCB Type in the PCB Library.
6. Establish the Carrier / Passenger relationship.
7. Verify the PCB references.

The resulting PCB definition is derived into the Adapter Plate automatically.

The PCB Library entry then becomes reusable for the enclosure workflow.

For the complete import procedure, see [KiCad Integration](kicad-integration.md).

---

# 🔁 Updating a PCB

When the PCB design is revised, the KiCad STEP model can normally be updated without redesigning the enclosure architecture.

The general workflow is:

```text id="x9w7a8"
KiCad PCB revision
       │
       ▼
New STEP export
       │
       ▼
Replace / update Passenger
       │
       ▼
PS KiCadStep
       │
       │ Carrier remains reusable
       ▼
Adapter Plate
       │
       ▼
PS Enclosure
       │
       ▼
Updated enclosure
```

If the PCB outline, mounting locations or coordinate system remain compatible, the existing PCB Library definition can continue to be used.

If the actual PCB definition changes, the PCB Library entry may need to be updated or replaced.

---

<p align="center">

<p>
<p align="center"><i>Updating the STEP model</i></p>

---

# 🧱 PCB Library and Adapter Plate

The PCB Library provides the PCB-specific references consumed by the Adapter Plate.

The Adapter Plate then translates those references into the mechanical interface required by the enclosure.

```text id="yflj28"
PCB Library
     │
     │ PCB definition
     ▼
Adapter Plate
     │
     │ mechanical interface
     ▼
PS Enclosure
```

This separation is important.

The Adapter Plate should not need to know how the PCB was designed in KiCad.

It only needs the stable PCB references provided by the PCB definition.

---

# ⚙️ PCB Configuration vs. Enclosure Configuration

PCB Type selection and orientation may be exposed through **PS Enclosure**, but the underlying PCB definition remains owned by the PCB Library.

For example:

### PCB Library

Defines:

- PCB Type
- PCB geometry
- Mounting locations
- Reference coordinate system
- PCB-specific information

### PS Enclosure

Selects and uses that definition and controls:

- PCB rotation
- Component side
- Mounting side
- Adapter Plate height
- Box height
- Lid fastening
- Inserts
- Cut-outs
- Labels

This distinction keeps the PCB reusable across different enclosure configurations.

---

# 🧠 Design Principles

## Reusable

A PCB Library entry should be reusable by multiple Boxify enclosure configurations.

## PCB-specific

The library should contain information about the PCB, not the enclosure.

## Stable

Reference geometry and coordinate systems should remain stable between compatible PCB revisions.

## Independent

The PCB definition should not depend on a particular enclosure design.

## Minimal

Only information required to define and interface the PCB should be stored in the library.

## Parametric

Where practical, PCB-specific geometry should be driven by parameters and stable references rather than manually duplicated dimensions.

---

# 🎯 Result

The PCB Library provides a stable and reusable definition of the PCB that sits between the electronic design and the mechanical enclosure.

Its role can be summarized as:

```text id="k8e8qf"
              KiCad
                │
                │ detailed STEP
                ▼
          PS KiCadStep
                │
                │ Passenger
                ▼
       ┌─────────────────┐
       │   PCB Library   │
       │                 │
       │     Carrier     │
       └────────┬────────┘
                │
                │ PCB definition
                ▼
         Adapter Plate
                │
                │ mechanical interface
                ▼
          PS Enclosure
                │
                ▼
        Box Base + Lid
```

The key principle is:

> **The PCB Library defines what the PCB is; PS Enclosure defines what the enclosure should be.**

This separation allows the same PCB definition to be reused across different enclosure configurations while keeping the enclosure independent from the PCB implementation.

---

## 🧩 Adding a New PCB Type

A new PCB Type can be added to the PCB Library without modifying the overall Boxify architecture.

A typical workflow is:

1. Create a new PCB Type in the PCB Library.
2. Define the PCB dimensions and relevant mounting/interface geometry.
3. Position the PCB Library Mate Connector at the **center of the PCB**.
4. Add the required configuration variables and options.
6. Verify the resulting Adapter Plate and enclosure geometry.
7. Verify the result in the Assembly.

The PCB Type acts as the **Carrier** for the actual PCB geometry used by Boxify. It provides the stable, reusable PCB definition on which the surrounding enclosure architecture depends.

When using an imported KiCad STEP model, make sure the PCB Type **has the same dimensions as the PCB in the STEP model** and that the PCB origin is centered accordingly.

The goal is to add a new PCB definition to the library rather than creating a separate, hard-coded implementation in the enclosure.

---

# 📚 Related Documentation

- 📄 [Getting Started](getting-started.md)
- 📄 [Architecture](architecture.md)
- 📄 [Adapter Plate](adapter-plate.md)
- 📄 [Enclosure](enclosure.md)
- 📄 [Threaded Insert Library](threaded-insert-library.md)
- 📄 [KiCad Integration](kicad-integration.md)
- 📄 [Configurations](configurations.md)

---

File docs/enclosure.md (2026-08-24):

# 📦 Enclosure

## 🧠 Purpose

The **Enclosure** is the final mechanical stage of the Boxify framework.

It converts the mechanical interface provided by the **Adapter Plate** and the user-selected configuration in **PS Enclosure** into a complete parametric enclosure consisting of:

- **Box Base**
- **Box Lid**

The Base and Lid are designed together because they always belong to the same enclosure configuration.

The enclosure adapts automatically to the PCB Type provided by the upstream PCB definition, the Adapter Plate and the enclosure configuration.

---


<p align="center"><i>Enclosure for the PCB with cut-outs and textlabels</i></p>

---

# 🏗 Enclosure Architecture

The enclosure is generated from the information provided by the preceding stages of the Boxify architecture.

```text
PS KiCadStep  <--- PCB Library
     │
     │ PCB geometry
     ▼
Adapter Plate
     │
     │ mechanical interface
     ▼
PS Enclosure  <--- Threaded Insert Library
     │
     │ user configuration
     ▼
┌─────────────────────────┐
│                         │
│     Box Base + Lid      │
│                         │
└─────────────────────────┘
```

The enclosure does not need to understand the detailed implementation of the PCB.

It uses the **Adapter Plate as the mechanical abstraction layer**.

This keeps the enclosure independent from the PCB implementation while allowing it to adapt to different PCB designs.

---

# ⚙️ PS Enclosure

**PS Enclosure** is the main user-facing Part Studio for configuring and generating the enclosure.

Enclosure-related configuration is centralized here.

Typical configuration options include:

- PCB rotation
- Component side up or down
- Mounting side above or below the adapter plate
- Adapter Plate height
- Box height
- Wall thickness
- Lid fastening type
- Threaded insert configuration
- Interface cut-outs
- Text labels

The available configuration options can change dynamically depending on other selections.

This prevents irrelevant settings from being presented to the user.

---

# 🧱 Box Base

The **Box Base** contains the main body of the enclosure.

It is generated relative to the Adapter Plate and the selected enclosure configuration.

Typical Base features include:

- Bottom
- Side walls
- Mounting structure
- PCB / Adapter Plate support
- Enclosure lugs
- Threaded insert pockets
- Interface cut-outs
- Text labels

The Base dimensions are derived from the configured PCB and Adapter Plate geometry wherever possible.

This allows the Base to adapt automatically when the upstream geometry changes.

---

# 🛡️ Box Lid

The **Box Lid** closes the enclosure and is generated as part of the same enclosure configuration as the Base.

The Lid can contain:

- Lid plate
- Fastening features
- Screw pockets
- Countersinks or counterbores
- Cut-outs
- Text labels

The Lid is designed together with the Base so that fastening features, wall geometry and clearances remain coordinated.

---

# 🔩 Lid Fastening

The Lid fastening system is configuration-driven.

The user selects a **Lid Fastening Type**, and Boxify generates the corresponding geometry.

Possible configurations can include:

- **None**
- **Counterbore screws**
- **Countersunk screws**
- **Selftapping screws**

The exact options can evolve as additional fastening methods are added.

The important principle is that the user selects the **fastening method**, not the individual CAD features required to implement it.

---

## Dynamic Fastening Features

Fastening-related features are dynamically suppressed when they are not required.

For example:

```text
Lid Fastening Type
       │
       ├── None
       │       └── Screw-related features suppressed
       │
       ├── Counterbore screws
       │       └── Counterbore geometry enabled
       │
       └── Countersunk screws
               └── Countersink geometry enabled
```

This allows several lid variants to be generated from the same parametric feature structure.

---

# 🔩 Threaded Inserts

Threaded inserts are optional.

The **Threaded Insert Library** provides reusable insert definitions that can be selected from the enclosure configuration.

The selected insert definition determines the geometry required to accommodate the insert.

```text
Threaded Insert Library
          │
          │ reusable insert definition
          ▼
     PS Enclosure
          │
          ▼
 Insert pockets / mounting geometry
```

Threaded inserts can also be disabled completely.

When inserts are disabled, insert-related features are dynamically suppressed.

This makes it possible to use the same enclosure model for:

- Enclosures with threaded inserts
- Enclosures without threaded inserts

---

<p align="center"><i>Section view of Enclosure with Threaded Inserts</i></p>

---

# 🔌 Interface Cut-outs

Boxify allows the user to define interface cut-outs based on a **projection of the relevant PCB / KiCad geometry**.

The required interface geometry is projected into Boxify, where the user defines the corresponding cut-out. The cut-out is then positioned relative to the **Adapter Plate and enclosure**, rather than being manually placed against the final enclosure walls.

This makes the cut-outs more robust when enclosure dimensions or configurations change.

Because the cut-out is derived from the PCB geometry, it **propagates with the PCB** when the PCB position or configuration changes.

Where the required geometry is available from the PCB / KiCad integration, the cut-out can therefore remain associated with the **interface it represents**, rather than with a fixed location in the enclosure.

> **PCB geometry → projection → user-defined cut-out → parametric enclosure**
---

# 🏷️ Text Labels

Boxify allows the user to **define optional text labels** as part of the enclosure configuration.

Labels can be used for:

- Connector identification
- Button identification
- Orientation markings
- Project information
- Other enclosure-specific information

Labels belong to the **enclosure configuration** rather than the PCB Library because they describe the physical enclosure, not the PCB itself.

This keeps enclosure-specific labelling independent from the PCB definition and allows labels to be configured together with the enclosure.

---

# 📐 Parametric Dimensions

The enclosure is driven by a combination of configuration variables and derived/measured geometry.

Typical configurable dimensions include:

- Box height
- Wall thickness
- Bottom thickness
- Lid thickness
- Adapter Plate height

Other dimensions should preferably be derived from existing geometry.

For example:

```text
PCB geometry
     │
     ▼
Adapter Plate geometry
     │
     ├── measured PCB Thickness
     ├── mounting positions
     └── reference geometry
             │
             ▼
       Enclosure geometry
```

This avoids duplicating dimensions throughout the model.

---

# 🔄 Base and Lid Relationship

The Box Base and Box Lid are intentionally kept together in the same Part Studio.

This provides a shared design context for features that must remain coordinated.

Examples include:

- Overall enclosure dimensions
- Wall thickness
- Lug position
- Fastening locations
- Screw clearance
- Insert positions
- Lid fit
- Cut-out locations

A change to the enclosure configuration can therefore update both Base and Lid together.

---

# 🧩 Feature Organization

Related enclosure features should remain grouped logically.

A typical feature structure can contain groups such as:

```text
Enclosure
│
├── References
│
├── Box Base
│   ├── Bottom
│   ├── Walls
│   ├── Lugs
│   └── Insert Features
│
├── Box Lid
│   ├── Lid
│   ├── Fastening
│   └── Optional Features
│
├── Cut-outs
│
└── Labels
```

The exact feature structure can evolve as the enclosure develops.

The important principle is that related features remain together and their order remains understandable.

---

# ⚙️ Dynamic Feature Suppression

Boxify uses **dynamic suppression** to keep optional features under control.

A configuration can determine whether a feature or feature group is relevant.

For example:

```text
Configuration
     │
     ├── Inserts = None
     │       └── Insert features suppressed
     │
     ├── Lid fastening = Countersunk Screws
     │       ├── Counterbore suppressed
     │       └── Countersink enabled
     │
     └── Labels = No
             └── Label features suppressed
```

This means one enclosure model can support multiple valid configurations without requiring separate versions of the feature tree.

---

# 🧠 Design Principles

The enclosure follows several important principles.

### Configuration-driven

The enclosure is generated from user-selected configuration rather than manually edited geometry.

### Adapter Plate driven

The enclosure uses the Adapter Plate as its mechanical reference.

### Base and Lid together

The Base and Lid share the same design context and configuration.

### Optional features

Features that are not required are dynamically suppressed.

### Reusable libraries

Reusable components such as threaded inserts are provided through libraries rather than hard-coded into the enclosure.

### Derived geometry

Where possible, geometry is derived or measured rather than duplicated as independent variables.

### Minimal manual intervention

Normal enclosure configuration should not require editing Derive features, sketches or internal implementation details.

---

# 🎯 Result

The result is a configurable enclosure that can adapt to different electronics without rebuilding the enclosure architecture from scratch.

The same Boxify framework can therefore produce variants such as:

```text
                    Boxify Enclosure
                           │
          ┌────────────────┼────────────────┐
          │                │                │
          ▼                ▼                ▼
     No Inserts       With Inserts      Different PCB
          │                │                │
          └────────────────┼────────────────┘
                           │
                           ▼
                  Configured Base + Lid
```

The geometry changes according to the selected configuration while the underlying enclosure architecture remains reusable.

---

# 📚 Related Documentation

- 📄 [Getting Started](getting-started.md)
- 📄 [Architecture](architecture.md)
- 📄 [PCB Library](pcb-library.md)
- 📄 [Adapter Plate](adapter-plate.md)
- 📄 [Threaded Insert Library](threaded-insert-library.md)
- 📄 [KiCad Integration](kicad-integration.md)
- 📄 [Configurations](configurations.md)

---

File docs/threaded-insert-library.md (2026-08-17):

# 🔩 Threaded Insert Library

## 🧠 Purpose

Boxify supports optional **threaded inserts** for securing the enclosure.

The **Threaded Insert Library** contains reusable definitions for supported insert types. These definitions are consumed by **PS Enclosure** when threaded inserts are enabled.

This separates the reusable insert geometry from the enclosure itself.

The result is a flexible system in which the same enclosure architecture can be generated:

- Without threaded inserts
- With different threaded insert types
- With different insert configurations as the library expands

---



<p align="center"><i>Boxify Threaded inserts Library</i></p>

---

# 🏗 Position in the Boxify Architecture

```text
PCB / KiCad
     │
     │ detailed STEP
     ▼
PS KiCadStep  <--- PCB Library
     │
     │ PCB definition
     ▼
Adapter Plate
     │
     │ mechanical interface
     ▼
PS Enclosure  <--- Threaded Insert Library
     │
     │ user configuration
     ▼
Box Base + Box Lid
     │
     ▼
Assembly
```

The **Threaded Insert Library** supports PS Enclosure in the same way that the **PCB Library** supports PS KiCadStep.

The library provides reusable definitions; PS Enclosure determines how those definitions are used.

---

# 📚 Threaded Insert Library

The Threaded Insert Library contains reusable definitions for threaded inserts.

A library entry can define:

- Insert type
- Thread size
- Insert dimensions
- Recommended pocket dimensions
- Installation geometry
- Reference geometry
- Other insert-specific parameters

The library should describe the **physical insert**, rather than the enclosure in which it will be used.

---

# 🔩 Insert Definition

A threaded insert definition represents the geometry required to accommodate a particular insert.

For example:

```text id="z8q4mn"
Threaded Insert
     │
     ├── Thread size
     ├── Outer diameter
     ├── Length
     ├── Pocket diameter
     └── Pocket depth
```

The exact parameters depend on the insert type.

The purpose is to provide a reusable definition that can be consumed by the enclosure features.

---

# ⚙️ Configuration

Threaded insert configuration is controlled from **PS Enclosure**.

The user can select whether threaded inserts are required and, when enabled, which insert definition should be used.

```text id="4x0j9k"
PS Enclosure
     │
     │ Insert configuration
     ▼
Threaded Insert Library
     │
     │ selected insert definition
     ▼
Enclosure insert geometry
```

This keeps the user-facing configuration centralized.

The user should not normally need to edit the Threaded Insert Library when configuring an enclosure.

---

# 🚫 No Inserts

Threaded inserts are optional.

The enclosure can be configured with:

> **No Inserts**

When inserts are disabled, all insert-related features are dynamically suppressed.

```text id="h7p2qw"
Insert Configuration
        │
        ├── No Inserts
        │      │
        │      └── Insert features suppressed
        │
        └── Insert selected
               │
               └── Insert geometry enabled
```

This allows the same enclosure model to support both insert and non-insert variants.

---

# 🔄 Dynamic Suppression

Boxify uses **dynamic suppression** to control insert-related features.

When threaded inserts are not required:

- Insert pockets are suppressed.
- Insert-related lug features are suppressed where applicable.
- Other insert-dependent geometry is suppressed.

When inserts are enabled, the corresponding features become active.

This avoids maintaining separate enclosure models for different insert configurations.

---

# 🧱 Insert Geometry

The enclosure does not simply model the threaded insert itself.

Instead, Boxify generates the **mechanical accommodation geometry** required to install the selected insert.

Depending on the insert definition, this can include:

- Insert pocket
- Bore
- Counterbore
- Installation clearance
- Supporting lug geometry

The insert definition therefore drives the geometry required by the enclosure.

---

# 📍 Insert Locations

Insert locations are determined by the enclosure architecture.

The Threaded Insert Library defines **what the insert is**.

The enclosure defines **where the insert is used**.

This distinction is important:

```text id="6r9m2d"
Threaded Insert Library
        │
        │ What?
        ▼
   Insert definition

PS Enclosure
        │
        │ Where?
        ▼
   Insert locations
```

Insert locations therefore remain part of the enclosure design rather than becoming part of the reusable insert library.

---

# 🔄 Configuration Flow

The complete relationship is:

```text id="x4v8pc"
Threaded Insert Library
          │
          │ reusable definition
          ▼
     PS Enclosure
          │
          │ user configuration
          ▼
   Insert feature logic
          │
          ▼
     Box Base / Lid
```

This allows the library to remain independent of any particular enclosure.

---

# 🧩 Adding a New Insert Type

A new insert type can be added to the library without redesigning the overall enclosure architecture.

A typical workflow is:

1. Add the new insert definition to the Threaded Insert Library.
2. Define its relevant dimensions and installation geometry.
3. Make the definition available to PS Enclosure.
4. Add the new option to the appropriate configuration.
5. Use the **Lug Verification Help** to verify that the insert and surrounding lug geometry are correctly sized and positioned.
6. Verify the generated enclosure geometry.
7. Verify the result in the Assembly.

The **Lug Verification Help** provides a visual check of the insert installation geometry and helps identify potential clearance or positioning issues before finalizing the enclosure.

The enclosure should consume the new definition rather than containing a completely separate hard-coded implementation.
<p align="center">

<p>
<p align="center"><i>Lug Verification Help</i></p>

---

# 🧪 Verification

When using a threaded insert configuration, verify:

- Insert type
- Thread size
- Insert pocket diameter
- Insert pocket depth
- Insert position
- Lug Verification Help
- Lug geometry
- Wall thickness around the insert
- Screw clearance
- Lid alignment
- Installation accessibility

The final result should always be verified in the Assembly.

---

# 🧠 Design Principles

## Reusable Definitions

The library contains reusable insert definitions rather than project-specific enclosure geometry.

## Centralized Configuration

Insert selection belongs to **PS Enclosure**.

## Separate "What" and "Where"

The library defines **what the insert is**.

The enclosure defines **where it is used**.

## Optional by Design

Threaded inserts are an optional enclosure feature.

## Dynamic

Insert-related features should be dynamically suppressed when inserts are disabled.

## Parametric

Insert geometry should be driven by the insert definition rather than duplicated manually in enclosure features.

## Extensible

New insert types should be addable without fundamentally changing the enclosure architecture.

---

# 🎯 Result

The Threaded Insert Library allows Boxify to support different fastening hardware while keeping the enclosure architecture reusable.

The complete relationship can be summarized as:

```text id="8m2k7v"
                    Threaded Insert
                       Library
                          │
                          │ What?
                          ▼
                    Insert Definition
                          │
                          ▼
                     PS Enclosure
                          │
                          │ Where?
                          ▼
                   Insert Locations
                          │
                          ▼
                  Insert Pocket Geometry
                          │
                          ▼
                    Box Base + Lid
```

The key principle is:

> **The Threaded Insert Library defines the insert; PS Enclosure decides whether and where it is used.**

This keeps reusable hardware definitions separate from enclosure-specific design decisions.

---

# 📚 Related Documentation

- 📄 [Getting Started](getting-started.md)
- 📄 [Architecture](architecture.md)
- 📄 [PCB Library](pcb-library.md)
- 📄 [Adapter Plate](adapter-plate.md)
- 📄 [Enclosure](enclosure.md)
- 📄 [KiCad Integration](kicad-integration.md)
- 📄 [Configurations](configurations.md)

---

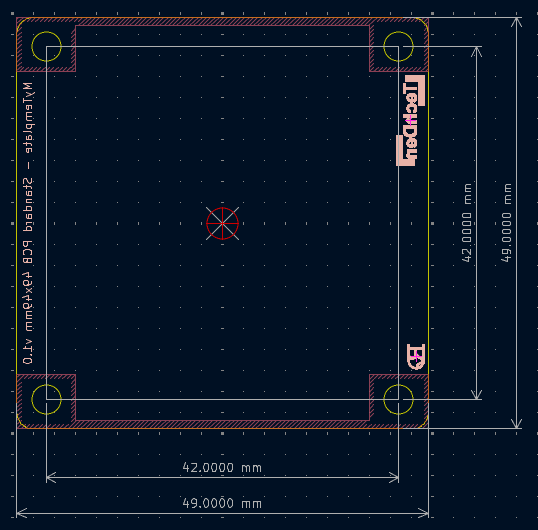
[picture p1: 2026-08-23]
KiCad/templates/Panel PCB w49x49mm/meta/brd.png

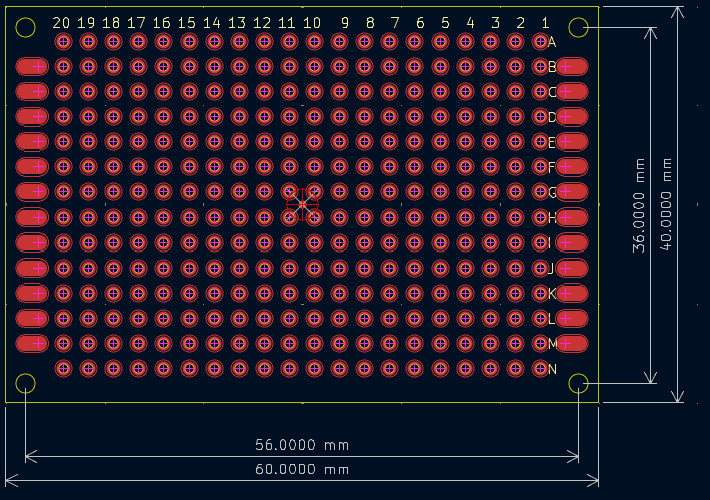
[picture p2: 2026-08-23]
KiCad/templates/Prototype PCB w40x60mm/meta/brd.png

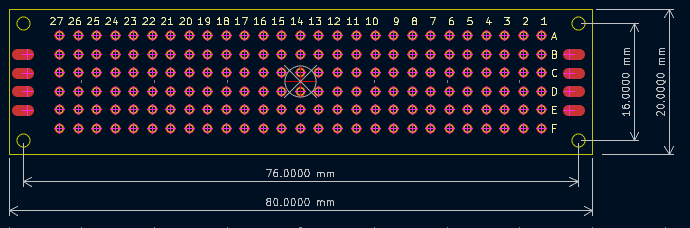
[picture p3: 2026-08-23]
KiCad/templates/Prototype PCB w20x80mm/meta/brd.png

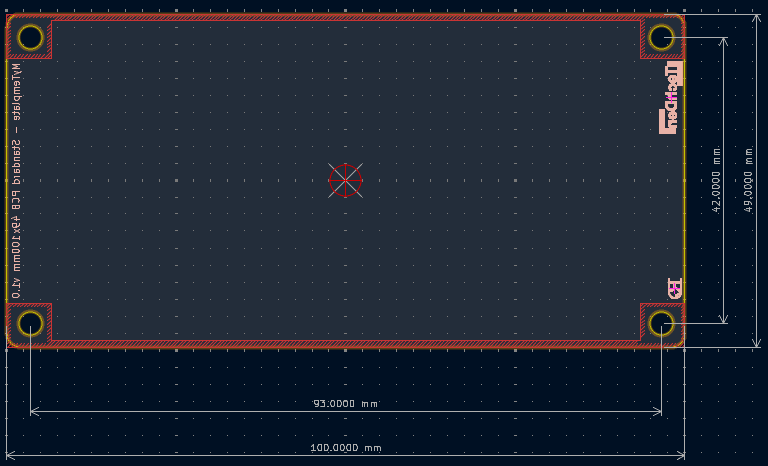
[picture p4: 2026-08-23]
KiCad/templates/Panel PCB w49x100mm/meta/brd.png

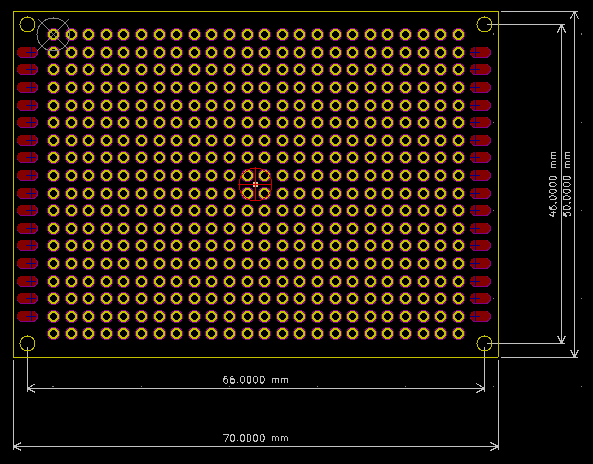
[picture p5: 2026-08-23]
KiCad/templates/Prototype PCB w50x70mm/meta/brd.png

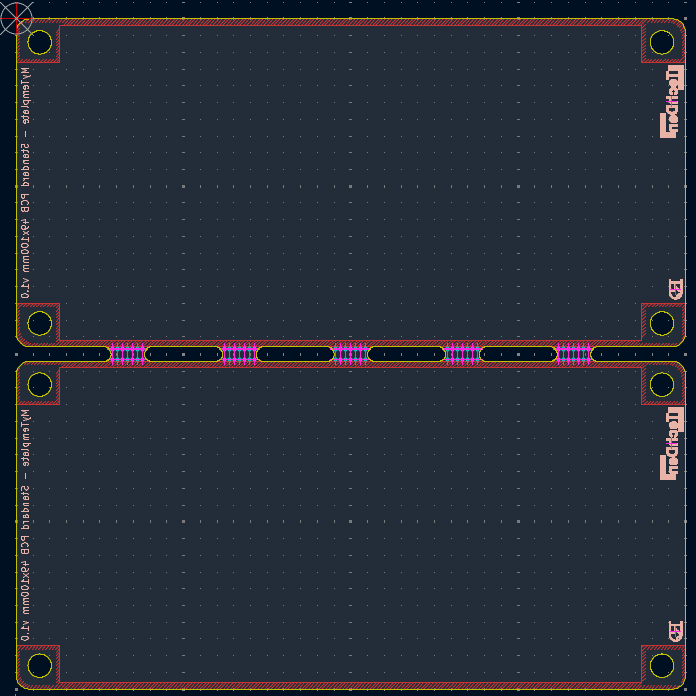
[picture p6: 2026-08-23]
KiCad/templates/Panel PCB w49x100mm/meta/panel.png

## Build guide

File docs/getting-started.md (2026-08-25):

# 🚀 Getting Started

Welcome to **Boxify**!

Boxify is a **Parametric Electronics Enclosure Framework (PEEF)** for Onshape that makes it easy to generate custom electronics enclosures around PCB-based electronics

Instead of designing a new enclosure for every project, Boxify separates the **electronics** from the **enclosure** using a reusable architecture based on an **Adapter Plate**.

The Boxify workflow is configuration-driven: enclosure-related settings are managed from **PS Enclosure**, while the underlying Part Studios provide the reusable geometry and libraries.

---


<p align="center"><i>Boxify Enclosure design</i></p>

---

# 📋 Prerequisites

Before using Boxify, you should have:

- An Onshape account
- Basic knowledge of Onshape Part Studios and Assemblies
- A PCB design
- A STEP model of the PCB
- KiCad is recommended for PCB and STEP generation

---

# 📂 Open the Boxify Document

Open the latest Boxify Onshape document using the link provided in the repository.

The document contains several Part Studios that together form the complete enclosure framework.

### Main components

- **PS Enclosure**
  - Main user-facing configuration point
  - Controls enclosure-related configuration
  - Generates the Box Base and Box Lid

- **PS Adapter Plate**
  - Provides the mechanical interface between the PCB and enclosure
  - Uses the selected PCB geometry and configuration

- **PS KiCadStep**
  - Integrates an imported PCB STEP model with a reusable PCB Library prototype
  - The STEP model acts as the **Passenger** on the PCB Library **Carrier**

- **PS LIBs**
  - **PS PCB Library**
  - **PS Threaded Insert Library**

The internal Part Studios normally do not need to be edited during regular enclosure configuration.

---

# 🔄 Typical Workflow

The normal Boxify workflow is:

```text
Create PCB
    │
    ▼
Export PCB as STEP
    │
    ▼
Import STEP into Boxify
    │
    ▼
Create / select PCB Library entry -> Derive it in PS KiCadStep and select PCB Type
    │
    ▼
Configure the enclosure in PS Enclosure
    │
    ├── PCB orientation and clearances
    ├── Adapter Plate height
    ├── Box height
    ├── Lid fastening
    ├── Threaded inserts
    ├── Cut-outs
    └── Labels
    │
    ▼
Generated Box Base + Box Lid
    │
    ▼
Verify in Assembly
```

You normally configure the complete enclosure from PS Enclosure. The PCB Type is selected once in the Derive feature of PS KiCadStep when setting up the PCB.

---

# 🧰 KiCad Templates and Panelization

Boxify provides a set of KiCad project templates matching the supported PCB Types in the PCB Library.

For panel PCBs, matching KiKit panelization configurations are also provided.

See [KiCad Resources](../KiCad/README.md)

---

# [1️⃣ Import your PCB](kicad-integration.md#importing-the-step-model)

Export your PCB from KiCad as a STEP model and import it into the Boxify document.

For best results:

- Make sure the PCB origin is always in the center of the PCB board (Boxify uses the centered Mate Connector in the PCB Library as the reference for mating the imported STEP model)
      <p align="center">
     
     </p>
      <p align="center"><i>Check Board center origin in the STEP export</i></p>
- Keep the PCB origin and coordinate system consistent between STEP exports.
- Include the PCB and all components that should be represented in the enclosure.
- Export using millimetres.
- Align the components that interface with the enclosure front to the same level in KiCad (before exporting) or manually in Onshape after importing

The imported STEP model becomes the detailed representation of the actual PCB assembly.

---



<p align="center"><i>STEP file of an example design on a prototype board</i></p>

---

# [2️⃣ Create a PCB Library Entry](kicad-integration.md#creating-a-pcb-library-entry)

Create a PCB Library entry for the imported PCB.

```text
Create / select PCB Library entry
    │
    ├── Prototype PCB type
    └── Panel PCB type (for panelized manufacturing)
```

Derive it in PS KiCadStep and select PCB Type

Boxify uses a **Carrier/Passenger architecture**:

- The PCB Library PCB is the reusable **Carrier**.
- The imported KiCad STEP model is the **Passenger**.
- The combination provides both reusable PCB reference geometry and the detailed representation of the actual PCB.

The PCB Library therefore becomes the reusable definition of the PCB used by the enclosure.

---

# [3️⃣ Configure the Enclosure](enclosure.md)

Open **PS Enclosure**.

This is the main configuration point for the Boxify enclosure.

Depending on the selected configuration, you can control parameters such as:

- PCB orientation
- Component side up or down
- Mounting side above or below the adapter plate
- Adapter Plate height
- Box height
- Box-wall, box-bottom and box-lid  thickness
- Lid fastening type
- Threaded insert configuration
- Interface cut-outs
- Text labels

Configuration variables and features are shown or suppressed dynamically according to the selected options.

This allows the same Boxify enclosure framework to support different enclosure variants without manually editing individual Part Studios or Derive features.

---
<p align="center">
  
</p>
<p align="center"><i>Adjust the Adapter Plate height and Box height so that everything fits properly.</i></p>

<p align="center">


</p>
<p align="center"><i>Adjust the PCB to Adapter Plate Edge Distance how far the PCB is positioned from the edge of the Adapter Plate</i></p>

---

# [4️⃣ Generate the Enclosure](enclosure.md)

The enclosure consists of:

- **Box Base**
- **Box Lid**

Both are generated from the common enclosure configuration and the geometry provided by the Adapter Plate.
The enclosure adapts automatically to the PCB Type provided by the upstream PCB definition.
The Box Lid and Base can be configured with different fastening options. Features that are not required by the selected configuration are automatically suppressed.

---

# [5️⃣ Configure Threaded Inserts](threaded-insert-library.md)

If threaded inserts are required, select the appropriate insert configuration from the **Threaded Insert Library**.

Boxify uses the selected insert definition to generate the corresponding mounting geometry.

Depending on the configuration, threaded inserts can be enabled or disabled without manually editing the enclosure features.

This makes it possible to use the same enclosure design for configurations with or without threaded inserts.

---

# 6️⃣ Verify the Enclosure in Assembly

After generating the enclosure, open the **Assembly**.

Insert or verify:

- Box Base
- Adapter Plate
- PCB
- Box Lid

The Assembly provides the final verification of the generated enclosure.

Check:

- Clearances
- Component fit
- PCB position
- Screw and insert alignment
- Lid fit
- Interface cut-outs
- Overall dimensions

The Assembly is intended primarily as a **verification environment**. Configuration changes should normally be made in **PS Enclosure**.

---

# 🧭 Understanding the Boxify Workflow

The Boxify architecture separates the design into several responsibilities:

```text
PCB / KiCad
     │
     │ detailed PCB STEP
     ▼
PS KiCadStep  <--- PCB Library
     │
     │ PCB + reusable PCB Type
     ▼
Adapter Plate
     │
     │ mechanical interface
     ▼
PS Enclosure <--- Treaded Insert Library
     │
     │ user configuration
     ▼
Box Base + Box Lid
     │
     ▼
Assembly
```

The key principle is:

> **Configure the enclosure from PS Enclosure; let the underlying architecture propagate the required geometry and configuration.**

This keeps the electronics, mechanical interface, enclosure generation, and final assembly clearly separated.

---

# 📚 Next Steps

For more information, continue with:

- 📄 [Architecture](architecture.md)
- 📄 [PCB Library](pcb-library.md)
- 📄 [Adapter Plate](adapter-plate.md)
- 📄 [Enclosure](enclosure.md)
- 📄 [Threaded Insert Library](threaded-insert-library.md)
- 📄 [KiCad Integration](kicad-integration.md)
- 📄 [Configurations](configurations.md)

---

# 💡 Tips

- Create an Onshape Version before making major changes.
- Configure the enclosure from **PS Enclosure** rather than editing downstream Part Studios.
- Use configuration variables instead of manually editing sketches or Derive features.
- Keep reusable geometry in the appropriate library.
- Group related features into logical folders.
- When developing new features, keep user configuration separate from engineering and measured variables.

---

**Happy Boxifying! 🚀**

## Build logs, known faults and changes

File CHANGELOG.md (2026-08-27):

# 📜 Changelog

All notable changes to Boxify are documented in this file.

The format is based on Keep a Changelog, adapted for the Boxify development process.

---

## [2.4] – Robust KiCad STEP Integration

### Changed
- Reworked KiCad STEP positioning to avoid downstream transformations of the imported Composite Part.
- Added `vs_pcbThickness` as an explicit PCB property used to calculate pcbMountAdjust.
- Removed the previous KiCad STEP transformation features.

### Improved
- Improved robustness when replacing or updating KiCad STEP models.
- Applied pcbRotation in the Adapter Plate derive feature in PS Enclosure rather than transforming the imported KiCad STEP.

---

## [2.3] – Simplified PCB Type Configuration

### Changed
- Moved **PCB Type selection** from PS Enclosure to the PCB Library Derive feature in PS KiCadStep.
- Removed the redundant PCB Type configuration from PS Enclosure, PS Adapter Plate and PS KiCadSTEP
- Simplified the process of **adding new PCB Types** by eliminating duplicate configuration maintenance.
- Improved separation between **PCB definition** and **enclosure configuration**.
- Updated the documentation to clarify the PCB Type selection and configuration workflow.

---

## [2.2] — KiCad Resources

### Added
- Added **KiCad project templates** matching the PCB definitions in the Boxify PCB Library.
- Added **KiKit panelization configurations** for supported Panel PCB types.
- Added a dedicated `kicad/` resource folder with documentation and usage instructions.
- Added documentation references linking the KiCad resources to the corresponding PCB Library definitions and KiCad integration workflow.

### Improved
- Simplified the workflow for creating Boxify-compatible PCBs in KiCad.
- Established a clear one-to-one naming relationship between Boxify PCB Library entries and their corresponding KiCad templates.
- Added ready-to-use KiKit configurations for panelized PCB designs.

---

## [2.1] – PCB Panelization Support

### Added
- Added **Panel PCB types** to the PCB Library for panelized PCB manufacturing.
- Added standard panel dimensions derived from a **100 × 100 mm manufacturing panel** with **2 mm mouse-bite spacing**:
  - Panel w100×100mm
  - Panel w49×100mm
  - Panel w49×49mm
  - Panel w23.5×49mm
  - Panel w23.5×23.5mm
- These configurations support common panel layouts such as **2×1, 2×2, 4×2 and 4×4** PCB arrangements.

### Improved
- Clearly separated **Prototype** PCB types from **Panel** PCB types in the PCB Library.
- Made it easier to configure Boxify for PCBs intended to be manufactured as a panel.

---

## [2.0] – Unified Enclosure Configuration

### Added

- Introduced a unified **Enclosure Configuration** workflow where all user-configurable enclosure options are available directly from **PS Enclosure**.
- Added configurable **Lid Fastening Types**, allowing different screw mounting strategies to be selected from a single configuration.
- Added support for **None**, **Counterbore screws**, **Countersunk screws** and **Selftapping screws** lid fastening options through automatic feature suppression.
- Added configurable automatic **lid text labels**.
- Added configurable automatic **interface cut-outs**.
- Added dynamic configuration visibility, showing only parameters relevant to the selected configuration.
- Added support for configuration-driven feature suppression, enabling multiple enclosure variants from a single Part Studio.

### Changed

- Centralized all enclosure-related configuration into **PS Enclosure**.
- Eliminated the need to switch between Part Studios during normal enclosure configuration.
- Eliminated manual editing of **Derive** features when changing enclosure options.
- Converted enclosure options into fully configuration-driven feature sets.
- Simplified the enclosure workflow into a single configuration interface.
- No Generic variables in Variable Studio needed anymore by using measuredVariables

### Improved

- Cleaner and more intuitive configuration experience.
- Reduced visual clutter by hiding irrelevant configuration variables.
- Improved maintainability through dynamic feature suppression.
- Increased scalability for adding future enclosure options without changing the overall architecture.
- Further strengthened the separation between framework logic and user configuration.
- Boxify now behaves as a configurable enclosure generator rather than a collection of parametric Part Studios.

---

## [1.7] – Automatic Interface Cut-outs

### Added

- Added automatic Box Lid cut-out generation based on the imported KiCad STEP assembly.
- Introduced a dedicated **Interface Projection** workflow using projected sketches to generate enclosure openings.
- Added support for automatic propagation of lid cut-outs when the PCB orientation changes.
- Added configurable front interface alignment within **PS KiCadStep**, providing a single reference for enclosure interfaces.

### Changed

- Moved front interface alignment from **PS Enclosure** to **PS KiCadStep**, making imported electronics responsible for their own interface positioning.
- Simplified the enclosure workflow by separating interface preparation from enclosure generation.
- Consolidated all lid openings into a single parametric cut-out sketch and extrusion.

### Improved

- Improved robustness against updated KiCad STEP imports while preserving enclosure references.
- Cleaner separation between imported electronics and enclosure geometry.
- Automatic regeneration of lid cut-outs after PCB rotation or STEP updates.
- Reduced feature count and improved maintainability of enclosure cut-out generation.
- Enhanced design workflow by allowing enclosure dimensions to be optimized interactively using the Adapter Plate position.

---

## [1.6] - KiCad STEP Integration

### Added

- Added support for importing KiCad STEP models into Boxify.
- Introduced a dedicated **PS KiCadStep** workflow for integrating imported electronics.
- Imported STEP models are converted into a **Composite Part**, keeping the Parts list clean and manageable.
- Added support for coupling an imported STEP model to a selected PCB from the PCB Library, allowing the STEP model to act as a visual representation ("passenger") of the PCB reference.

### Changed

- Electronics are now assembled in a dedicated intermediate Part Studio before being derived into the Adapter Plate.
- The Adapter Plate now derives the complete PCB + KiCad STEP assembly instead of separate PCB geometry.
- Moved PCB orientation (rotation) from the PCB workflow to **PS Enclosure**, making board orientation an enclosure-level configuration.
- Renamed **PS Box** to **PS Enclosure** to better reflect its responsibility for enclosure-level configuration and positioning.

### Improved

- Cleaner project organization using dedicated folders for Part Studios and CAD imports.
- Greatly reduced Parts list clutter by encapsulating imported STEP assemblies into Composite Parts.
- Improved separation between reusable framework components and project-specific electronics.
- Established a scalable architecture for future projects using imported KiCad assemblies without changing the enclosure workflow.

---

## [1.5] - Threaded Insert Library

### Added

- Reusable Threaded Insert Library
- Parametric insert definitions
- Automatic insert pocket generation
- Configurable insert selection

### Improved

- Library-based insert architecture
- Separation between enclosure geometry and insert definitions

---

## [1.4] - Enclosure Architecture

### Added

- Fully parametric enclosure generation
- Shared Box Base / Box Lid architecture
- Improved enclosure feature organization

### Improved

- Better feature grouping
- Cleaner enclosure workflow
- Increased design robustness

---

## [1.3] - Threaded Insert Preparation

### Added

- Mounting lug architecture
- Initial insert placement strategy
- Boolean workflow experiments

### Improved

- Lug geometry
- Preparation for reusable insert library

---

## [1.2] - Parametric Box Base & Lid

### Added

- Unified Box Base and Box Lid Part Studio
- Configurable Box Height
- Configurable Adapter Plate Height
- Measured Adapter Plate Height
- Automatic Lug Height calculation
- Feature folders for improved organization

### Improved

- Shared design context
- Better separation between user variables and engineering variables
- Improved maintainability

---

## [1.1] - Parametric Box Base

### Added

- First parametric Box Base
- Automatic wall generation
- Initial enclosure architecture

### Improved

- Integration with the Adapter Plate
- Foundation for future lid generation

---

## [1.0] - Stable Adapter Plate Architecture

### Added

- Configurable PCB Library
- Adapter Plate framework
- Measured PCB variables
- Configurable PCB Rotation
- Configurable Component Side
- Configurable Mount Side

### Improved

- Single source of truth for PCB geometry
- Robust configuration handling
- Generic enclosure architecture

---

## Pre-release History

### v0.3

- Introduced measured variables
- Improved variable ownership
- Reduced duplicated dimensions

### v0.2

- Introduced the Adapter Plate concept
- Separated PCB and enclosure architecture

### v0.1

- First configurable PCB Library
- Initial proof of concept

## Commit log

2026-08-03 Revise README for clarity and updated features
    Updated the README to clarify the purpose and features of Boxify, including the separation of electronics and enclosure, and added details about the Adapter Plate and its role. Removed unnecessary fr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
2026-08-03 Add documentation for PCB Library
    Introduced a new documentation file for the PCB Library, outlining its purpose, configuration options, and outputs.
2026-08-03 Add documentation for Adapter Plate
    Document the purpose, configuration, and outputs of the Adapter Plate.
2026-08-03 Add documentation for Threaded Insert Library
    Introduced documentation for the Threaded Insert Library, outlining its purpose, outputs, and supported insert types.
2026-08-03 Add architecture documentation for Boxify
    Added comprehensive architecture documentation for Boxify, detailing system components, data flow, parametric design principles, and related documentation.
2026-08-03 Enhance PCB Library documentation
    Expanded the PCB Library documentation to clarify its purpose, responsibilities, configuration options, outputs, and design principles.
2026-08-03 Enhance Adapter Plate documentation
    Expanded the documentation for the Adapter Plate, detailing its purpose, responsibilities, configuration options, reference geometry, measured variables, outputs, design principles, and related docum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
2026-08-03 Rename Box Lid to Enclosure and update details
    Updated documentation to reflect changes from 'Box Lid' to 'Enclosure', enhancing clarity on the enclosure's purpose, architecture, responsibilities, and future enhancements.
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2026-08-03 Add KiCad integration documentation
    This document outlines the integration of KiCad with Boxify, detailing the workflow for importing PCBs as STEP models, creating composite parts, and managing PCB library entries.
2026-08-03 Create roadmap.md for Boxify project
    Added a comprehensive roadmap for Boxify, outlining vision, guiding principles, current development focus, planned features, future ideas, community involvement, and long-term goals.
2026-08-03 Update CHANGELOG with new features and improvements
    Document notable changes and improvements in Boxify, including new features like KiCad STEP integration and a threaded insert library.
2026-08-03 Document design philosophy and framework architecture
    Added comprehensive design philosophy and framework architecture for Boxify, detailing goals, principles, and information flow.
2026-08-05 Update changelog for version 1.7 enhancements
    Improved robustness against updated KiCad STEP imports while preserving enclosure references. Enhanced design workflow by allowing enclosure dimensions to be optimized interactively using the Adapter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
2026-08-10 Update PCB specifications in getting started guide
    Removed PCB Rotation, Component Side, and Mount Side from the list.
2026-08-10 Update PCB Library entry instructions and descriptions
    Clarified instructions for deriving PCB Library Part and updated the description of the PCB Library entry.
2026-08-10 Add PCB selection configuration section
    Add configuration section for PCB selection in getting started guide.
2026-08-10 Revise workflow diagram for adapter plate process
    Updated workflow diagram to reflect changes in component names and processes.
2026-08-10 Add configuration variables section to KiCad integration
    Added a new item about passing configuration variables to downstream Part Studios.
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2026-08-10 Replace image in adapter-plate.md
    Updated the image in the adapter plate documentation.
2026-08-10 Fix formatting in KiCad integration documentation
2026-08-10 Revise workflow steps in adapter-plate.md
    Updated workflow diagram for clarity and consistency.
2026-08-10 Revise workflow for enclosure configuration
    Updated workflow diagram to include new steps for creating a composite part and a PCB library entry.
2026-08-10 Remove image from adapter-plate.md
    Removed an image from the adapter plate documentation.
2026-08-10 Enhance PCB library documentation with images
    Added images and description for PCB library.
2026-08-10 Replace 'Lip clearance' with 'PCB clearance'
2026-08-10 Enhance enclosure documentation with image and caption
    Added an image and caption for section view of enclosure.
2026-08-10 Replace image in enclosure.md
    Updated image reference in enclosure documentation.
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2026-08-11 Update workflow sections in kicad-integration.md
    Removed Workflow Overview section and added Position in the Workflow.
2026-08-12 Enhance README with Boxify enclosure image
    Added an image and description for Boxify enclosure design.
2026-08-12 Update architecture documentation by removing image
    Removed image and description for Boxify enclosure design.
2026-08-12 Enhance PCB Library documentation
    Updated PCB Library documentation with new images and clarified purpose.
2026-08-12 Enhance PCB library documentation with images
    Added images and a caption to the PCB library documentation.
2026-08-12 Revise Adapter Plate documentation for clarity
    Updated the Adapter Plate documentation to enhance clarity and detail, including images and additional explanations of design principles and parameters.
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2026-08-13 Fix link in getting-started.md for PCB import
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2026-08-13 Fix link case sensitivity in getting-started.md
2026-08-13 Fix formatting of section header for enclosure generation
2026-08-13 Fix Markdown headers in kicad-integration.md
    Updated section headers in kicad-integration.md to use proper Markdown formatting.
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2026-08-15 Fix capitalization in enclosure configuration section
2026-08-15 Correct capitalization of 'Type' in PCB section
2026-08-15 Correct capitalization of 'PCB Type' in documentation
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2026-08-17 Fix typos in threaded insert library documentation
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2026-08-17 Fix typo in enclosure section description
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2026-08-21 Fix formatting of prototype and panel dimensions
    Updated PCB dimensions formatting for consistency.
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2026-08-24 Replace image in adapter-plate.md
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
